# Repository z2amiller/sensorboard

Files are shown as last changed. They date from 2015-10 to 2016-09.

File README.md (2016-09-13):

# sensorboard
Sensor board using ESP8266
==========================

This is a simple sensor board using an ESP8266.

It is designed to run from 6 volts, or 4xAA batteries.  The software uses the
deep sleep functions of the ESP8266 for power savings, and applies power to the
sensors only when the ESP8266 is powered on.  It posts the sensor data to a 
[prometheus](http://prometheus.io/) [pushgateway](https://github.com/prometheus/pushgateway).
A copy of this sensor has run for more than two months on 4xAA batteries.
Longer life can be achieved by using a longer sleep interval; the ESP8266
consumes quite a bit of power at bootup and when communicating over wifi.

Hardware:
---------

* [ESP8266](https://github.com/esp8266/Arduino) is a fully featured wifi
  module with embedded microcontroller.  This project can make use of the
  [ESP-07](http://www.banggood.com/ESP8266-ESP-07-Remote-Serial-Port-WIFI-Transceiver-Wireless-Module-p-961247.html)
  module or any of the
  [ESP-12](http://www.banggood.com/ESP8266-ESP-12E-Remote-Serial-Port-WIFI-Transceiver-Wireless-Module-p-980984.html)
  variants - the extra pins at the bottom are unused.  If using the ESP-07
  with the always-on status LED, you may want to desolder / pry off the
  status LED to extend your battery life.
* [DHT22](http://www.electrodragon.com/product/dht22-pre-order-link/) is a
  temperature and humidity sensor.  It is actually the most expensive part
  of this board, even more expensive than the ESP8266.
* [BMP180](http://www.banggood.com/BMP180-Digital-Barometric-Pressure-Sensor-Module-Board-p-930690.html)
  is a barometric pressure and altitude sensor.
* [LMR16006YDDCR](http://www.ti.com/lit/ds/symlink/lmr16006.pdf) is a 600ma
  adjustable voltage switching power regulator.  While much more expensive
  than the LDO, batteries will last ~twice as long.
* [NR4018T100M](http://www.yuden.co.jp/productdata/catalog/en/wound04_e.pdf)
  is the 10uh inductor used as L1.
* [BME280](http://www.mouser.com/ds/2/783/BST-BME280_DS001-11-844833.pdf) is
  an integrated pressure, humidity, and temperature sensor.  Replaces the
  DHT22 and BMP180 in version 4.0.
* Onboard voltage meter to track the battery voltage.  R4 and R5 make up
  the voltage divider so should be 1% or better tolerance that are
  fairly stable with temperature. 
* Everything else on the board is simple and common.
* This board is intended to be hand-solderable. The smallest components are
  0603 and are marked with hand-soldering pads.

Software:
---------

* This is programmed in the Arduino environment.  It includes some standard
  Adafruit libraries (for DHT22 and BMP085).  The newer "unified" sensor
  libraries don't work with the ESP8266 yet, but the older ones work well.
* This sensorboard posts the data to a prometheus gateway for easy graphing
  and alerting.  The code to get the sensor values is pretty straightforward
  and could be pretty easily adapted to other monitoring systems such as
  Thingspeak or MQTT.
* The [prometheus libraries](https://github.com/z2amiller/libraries/tree/master/prometheus)
  libraries are available in my [libraries](https://github.com/z2amiller/libraries)
  repository. The required i2c library is there as well.

Programming:
------------

* The sensorboard has a 6 pin programming header, and included in this
  repository is a sensorboard\_programmer module intended to be connected to
  this programming header. 
* The sensorboard programmer pulls out the reset and programming pins.  To
  flash a new software version, connect the programmer and press and hold
  the 'PROG' button while hitting reset.  This will reboot the ESP8266 into
  flash mode.
* The sensorboard is designed to use this
  [CP2102 board](http://www.banggood.com/5Pcs-CJMCU-CP2102-USB-To-TTLSerial-Module-UART-STC-Downloader-p-980102.html)
  for the USB interface, and
  [these](http://www.banggood.com/100pcs-Mini-Micro-Momentary-Tactile-Tact-Switch-Push-Button-DIP-P4-p-917570.html)
  cheap tactile switches.  That USB module solders right into the programmer
  board but you could also wire up any USB breakout that supports 3.3 volts.
* Unfortunately the configuration is part of the code.  You'll have to change
  some of the constants in the code to use your wifi SSID/password,
  prometheus pushgateway, etc.

Versions:
---------

Check out the following branches for these released versions:

* [sensorboard-4.0](https://github.com/z2amiller/sensorboard/tree/sensorboard-4.0)
  [oshpark](https://oshpark.com/shared_projects/D1xuf056) UNTESTED:
  Replace the DHT22 and BMP180 with a BME280.  No longer hand-solderable,
  needs a hot air station for the FGA-8 footprint BME280.
* [sensorboard-3.1](https://github.com/z2amiller/sensorboard/tree/sensorboard-3.1)
  [oshpark](https://oshpark.com/shared_projects/4DUu3wyO) TESTED:
  Sensorboard with a switching power supply. Higher parts cost but ~1.6x
  battery life.
* [sensorboard-2.2](https://github.com/z2amiller/sensorboard/tree/sensorboard-2.2)
  [oshpark](https://oshpark.com/shared_projects/rGc3bDv8) TESTED:
  Sensorboard using a LDO for simple build and lower parts cost.

More Links:
-----------

* Order the [sensorboard programmer](https://oshpark.com/shared_projects/fjlzVR1e)
  on OSHPark!
* Check out the [ESP8266 commmunity](http://reddit.com/r/ESP8266) on Reddit!

TODO(z2amiller):
---------------

* Add a picture of the sensorboard in action.
* Add some screenshots of Prometheus graphs.
* Create a prometheus setup tutuorial.
* Create a prometheus dashboard for the ESP8266 sensor data.
* Finish up the code for sensorboard-4.0 with the BME280 sensor.
* Create a sensorboard programmer with a regulator to power the ESP8266
  through the 3v3 pin while programming.

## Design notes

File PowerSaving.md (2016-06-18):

# Power Saving tips for the ESP8266

## Software Tips

### Use DeepSleep.

This is the #1 recommendation when designing a low power ESP8266 application.
Note that this requires hardware changes, too.  GPIO16 must be tied to the RST
pin, and RST should be pulled HIGH externally.  The ESP8266 will pull GPIO16
LOW to reset the chip once the deep sleep timer expires.

Note that this means that the chip is totally reset when coming out of deep
sleep.

Example:
```C++
void sleepFunc() {
  // If this sleep happened because of timeout, clear the
  // Wifi settings.  (Maybe the AP channel changed, etc)
  if (elapsed >= MAX_LOOP_TIME_MS) {
    WiFi.disconnect();
  }
  ESP.deepSleep(480000000, WAKE_RF_DEFAULT);
  // It can take a while for the ESP to actually go to sleep.
  // When it wakes up we start again in setup().
  delay(5000);
}
```

### Do not call WiFi.begin() in setup().

The ESP8266 chip saves the last known wifi settings.  Calling WiFi.begin()
wipes those out.  By calling WiFi.begin() only when it was needed, I shaved
more than 2 seconds from the average amount of time it takes to associate with
the AP.  WiFi.begin() should be called only if the saved SSID does not match
the configured SSID.  You can check the configured SSID with the WiFi.SSID()
call.  Also, it is good practice to clear the saved WiFi settings if the timer
expires.  (See next section "Use watchdog timers")

Example:
```C++
#define WIFI_SSID           "Embedded Pie"
void setup(void) {
  ...
  if (WiFi.SSID() != WIFI_SSID) {
    WiFi.begin(WIFI_SSID, WIFI_PASSWORD);
    WiFi.persistent(true);
    WiFi.setAutoConnect(true);
    WiFi.setAutoReconnect(true);
  }
  ...
}
```

### Use watchdog timers.

Set a timer for the maximum amount of time your polling loop
should run.  This will prevent your device from sitting there for
hours at a time with the WiFi radio on trying to associte if your
AP is down, for example.  The ESP8266 has a built-in Ticker that
takes a timeout and a callback.

Example:
```C++
Ticker sleepTicker;
void setup(void) {
 sleepTicker.once_ms(120000, &sleepFunc)
 ...
}
```

## Hardware Tips

### Eliminate "power" or other always-on LEDs.

Some ESP modules (ESP-07) have an always on "power" LED.  These take around
10mA of current to run, or about 200 hours to drain a single AA battery.  If
you have a status LED on board, disable it by de-soldering it or cutting the
traces.  I have done this on an ESP-07 without affecting the module.

The LED on ESP-12x modules only blinks during serial transmission,
which is infrequent enough not to worry about.

### If using a linear regulator, use one with low quiescent current.

This means no [AMS1117](http://www.advanced-monolithic.com/pdf/ds1117.pdf)
linear regulator which has a quiescent current of 5mA.  Look for low quiescent
current parts.  If you are using a linear regulator, the
[SPX3819M5](https://www.exar.com/content/document.ashx?id=615)
has a fairly low quiescent current of 90uA and a wide voltage range -
up to 16V.  At 90uA, it will take about about two and a half years to
discharge AA batteries.

Other good choices for ESP8266 regulators:

* [MCP1700](http://ww1.microchip.com/downloads/en/DeviceDoc/20001826C.pdf)
  (up to 6V at 1.6uA quiescent) or the
  [MCP1702](http://ww1.microchip.com/downloads/en/DeviceDoc/22008E.pdf)
  (up to 13.2V at 2.0uA quiescent).  Both of these regulators can
  supply 250mA constant and short 500mA bursts, which is perfect for
  the ESP8266 with its short bursts of current draw while transmitting.
  These are available in fixed 3.3V versions.  Available in both surface
  mount and TO-92 packages for under $US0.50 in single quantity.

* [HT73333-A](http://www.angeladvance.com/HT73xx.pdf) is a fixed 3.3V
  250mA regulator with a 4uA quiescent current available cheaply from
  AliExpress.  Also available in both surface mount and TO-92 packages.

### Supply power to sensors from a GPIO pin if the draw is low enough.

Sensors such as the DHT22 and BMP180 have a non-trivial quiescent current,
especially the BMP180 in
[module form](http://www.electrodragon.com/product/bmp180-barometric-pressure-sensor-board/)
which has an integrated linear regulator with a 80uA quiescent current.  The
ESP8266 GPIO pins can source/sink a few mA, which is enough to drive these
sensors so by powering the sensors from a pin, the sensors are only running
when the chip is on.

Some sensors like the DHT22 take 1-2 seconds after power is applied to give a
reading, so this approach can have downsides.

### Use a low quiescent current switching power regulator.

This complicates the build but is significantly more efficient.  Using a linear
regulator, if your ESP is drawing 70mA at 3.3v, it will also draw 70mA at 6v,
with the regulator burning the extra power as heat.

When using a switching regulator, the draw becomes lower by a ratio of the
output to input voltage.  Assuming a 90% efficient switching regulator and a 6v
supply, drawing 70mA of 3.3v becomes:

    70mA * (3.3 / 6) * (1 / 0.9) = ~43mA input current @ 6V.

This is significant because even though the device is only on for a short
amount of time, overall power consumption is dominated by the device in the
active state.  For example, if the device is drawing 100uA (0.1mA) while
sleeping and 70mA while active, sleeps for 8 minutes between cycles, and is on
for 10 seconds every cycle:

    AA batteries = ~2000mAhours or 7.2 million mA seconds

Linear regulator:
    480 seconds * 0.1mA = 48mA seconds
    10 seconds * 70mA = 700mA seconds

    748 mA seconds / cycle = ~9,700 cycles on a AA battery, or about
    54 days on 4xAA batteries.

Switching regulator:
    480 seconds * 0.1mA = 48mA seconds
    10 seconds * 43mA = 430mA seconds

    478 mA seconds / cycle = ~15,000 cycles on a AA battery, or about
    85 days on 4xAA batteries.

Good switching regulators for the ESP8266:

* The [LMR16006](http://www.ti.com/lit/ds/symlink/lmr16006.pdf) is an adjustable
  output 600mA switching regulator that can take a very wide range of input
  voltages, up to 60V.  It has a quiescent current of 28uA.

* The [LM3671](http://www.ti.com/lit/ds/symlink/lm3671.pdf) is available in
  both fixed and adjustable models.  It only accepts up to 6V input but is
  perfect for a 5v or single LiPo powered device.  It has a quiescent current
  of only 16uA.

### Do not use all-in-one boards like the WeMos D1 Mini or NodeMCU.

These boards are excellent for prototyping, but they hae some real downsides
when deployed in a low power application.

First, they often have cheap regulators with high quiescent current, like the
AMS1117. (See above why this is bad).

Worse, these boards have an "always on" USB UART bridge like a CP2102.  The
CP2102 datasheet says that the quiescent current is around 20mA!  This means
that even if you have put your ESP8266 is in deep sleep mode, the other stuff
on the board is conspiring to draw 20-25mA and will run your batteries down
quickly.

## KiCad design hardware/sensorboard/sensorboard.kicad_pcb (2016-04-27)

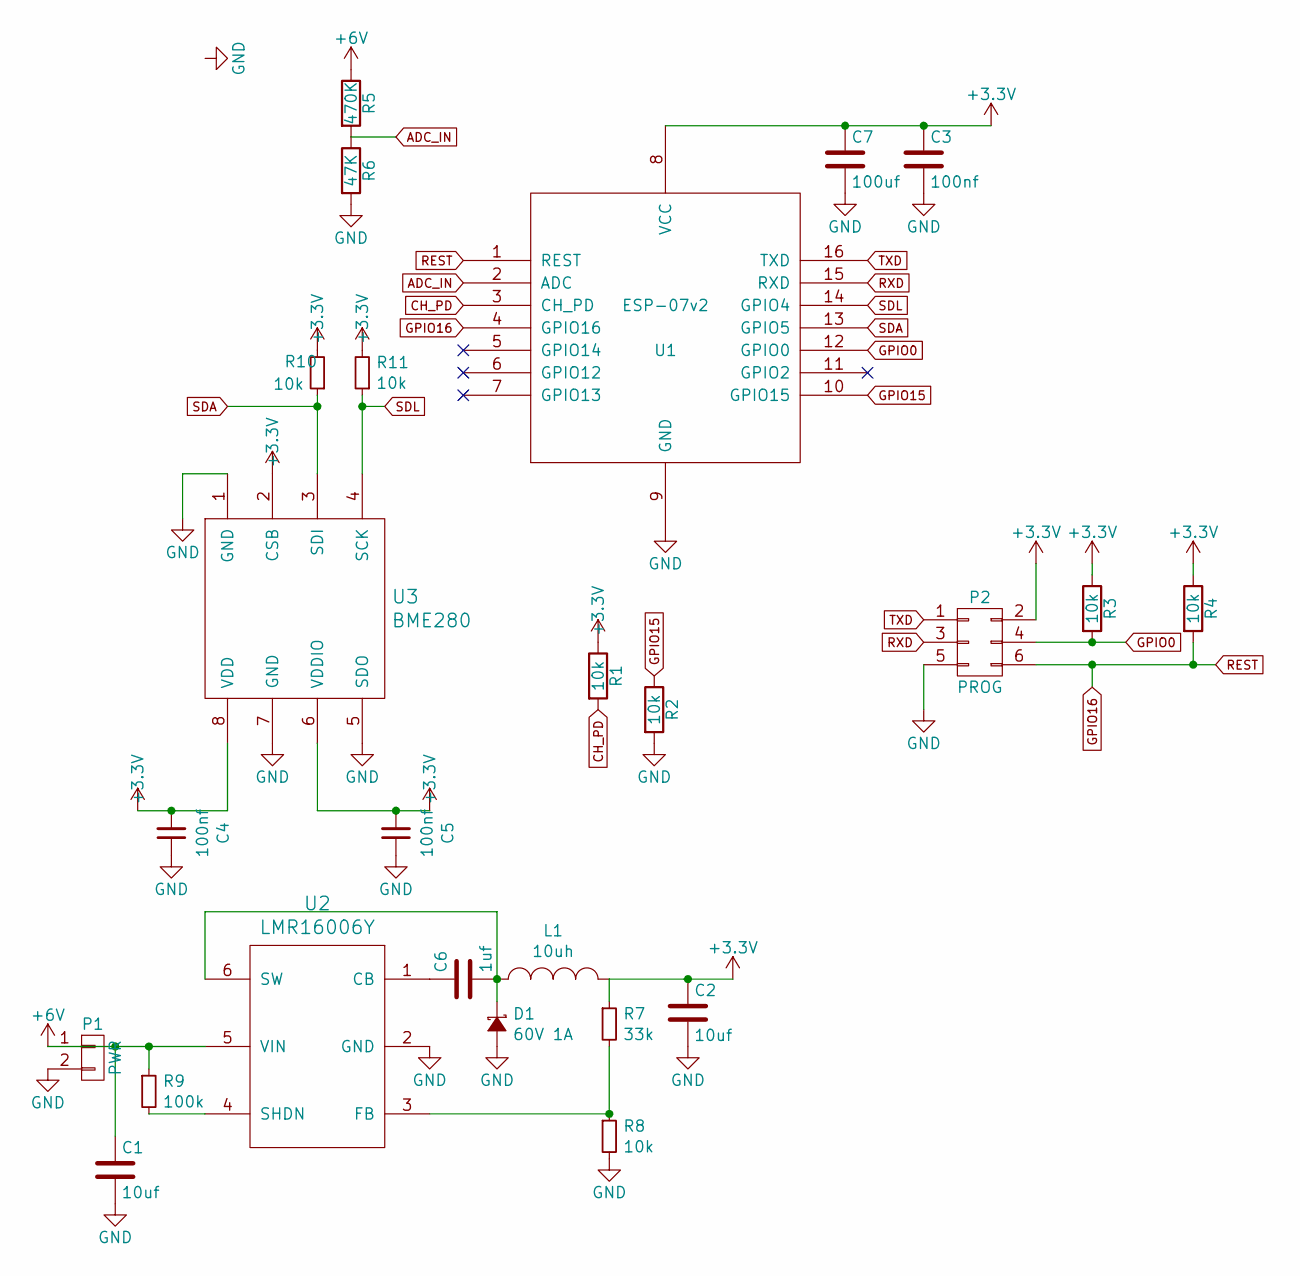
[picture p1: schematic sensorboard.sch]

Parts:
C1, C2: 10uf; C_0805_HandSoldering
C3, C4, C5: 100nf; C_0603_HandSoldering
C6: 1uf; C_0603_HandSoldering
C7: 100uf; TantalC_SizeD_EIA-7343_HandSoldering
D1: 60V 1A; SOD-123
L1: 10uh; NR8040_HandSoldering
P1: PWR; Pin_Header_Straight_1x02
P2: PROG; Pin_Header_Straight_2x03
R1, R2, R3, R4, R8, R10, R11: 10k; R_0603_HandSoldering
R5: 470K; R_0603_HandSoldering
R6: 47K; R_0603_HandSoldering
R7: 33k; R_0603_HandSoldering
R9: 100k; R_0603_HandSoldering
U1: ESP-07v2; ESP-12
U2: LMR16006Y; SOT-23-6
U3: BME280; FGA8

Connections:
+3V3: C2.1, C3.1, C4.2, C5.2, C7.1, L1.2, P2.2, R1.1, R3.1, R4.1, R7.1, R10.2, R11.2, U1.8 (VCC), U3.2 (CSB), U3.6 (VDDIO), U3.8 (VDD)
+6V: C1.1, P1.1, R5.1, R9.1, U2.5 (VIN)
ADC_IN: R5.2, R6.1, U1.2 (ADC)
CH_PD: R1.2, U1.3 (CH_PD)
GND: C1.2, C2.2, C3.2, C4.1, C5.1, C7.2, D1.2 (A), P1.2, P2.5, R2.2, R6.2, R8.2, U1.9 (GND), U2.2 (GND), U3.1 (GND), U3.5 (SDO), U3.7 (GND)
GPIO0: P2.4, R3.2, U1.12 (GPIO0)
GPIO15: R2.1, U1.10 (GPIO15)
GPIO16: P2.6, R4.2, U1.1 (REST), U1.4 (GPIO16)
unnamed: C6.1, U2.1 (CB)
unnamed: C6.2, D1.1 (K), L1.1, U2.6 (SW)
unnamed: R7.2, R8.1, U2.3 (FB)
unnamed: R9.2, U2.4 (SHDN)
RXD: P2.3, U1.15 (RXD)
SDA: R10.1, U1.13 (GPIO5), U3.3 (SDI)
SDL: R11.1, U1.14 (GPIO4), U3.4 (SCK)
TXD: P2.1, U1.16 (TXD)

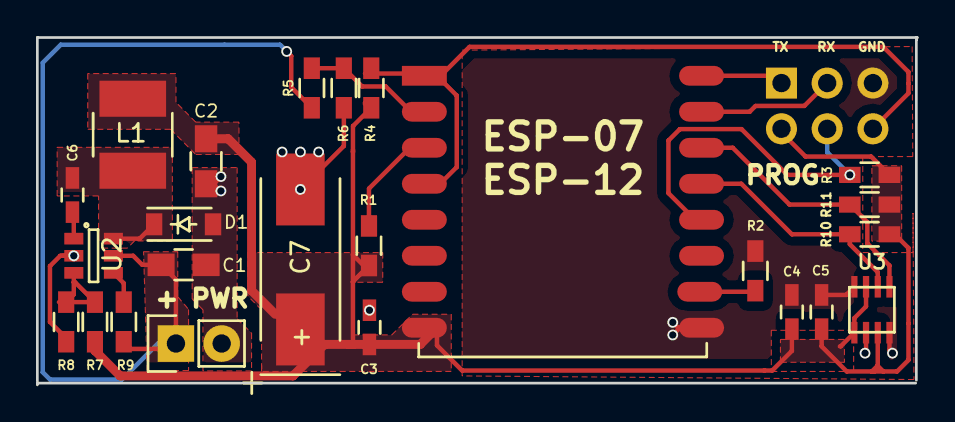
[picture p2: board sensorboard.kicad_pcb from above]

Board: 2 copper layers, 48.9 x 19.3 mm, 25 parts (1 on the bottom side), 16 nets.

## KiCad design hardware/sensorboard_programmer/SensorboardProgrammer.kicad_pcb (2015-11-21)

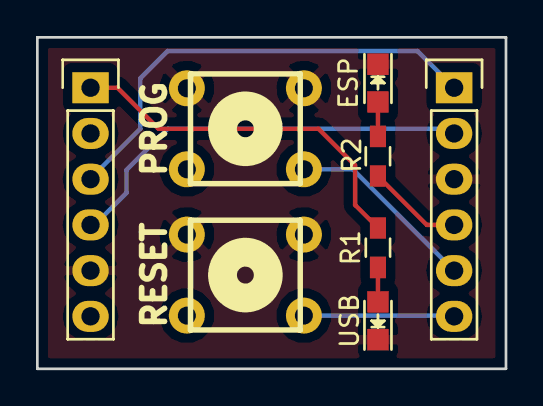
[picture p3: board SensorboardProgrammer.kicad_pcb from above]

Board: 2 copper layers, 26.0 x 18.4 mm, 8 parts (0 on the bottom side), 9 nets.

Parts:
ESP: ESP; LED-0805
P2: CONN_01X06; Pin_Header_Straight_1x06
PROG: SW_PUSH; PCB_PUSH
R1, R2: 100 ohm; R_0603_HandSoldering
RESET: SW_PUSH; PCB_PUSH
USB: USB; LED-0805
USB MODULE: CONN_01X06; Pin_Header_Straight_1x06

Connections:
GND: ESP.1, P2.3, PROG.2, PROG.4, RESET.2, RESET.4, USB.1, USB MODULE.5
unnamed: R1.1, USB.2
unnamed: ESP.2, R2.1
unnamed: R1.2, USB MODULE.1
unnamed: P2.4, R2.2
unnamed: P2.5, PROG.3
unnamed: P2.6, RESET.3
RXI: P2.1, USB MODULE.3
TXO: P2.2, USB MODULE.4

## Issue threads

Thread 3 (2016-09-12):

Link to prometheus arduino library used in this project

croisez, 2016-09-12:
Hi, could you document the link to the prometheus Arduino library used in this project?

z2amiller, 2016-09-13:
Added a link to the README.md.  (https://github.com/z2amiller/sensorboard/commit/1cc4190ea89385d12b81b523408ae3b3c466286c)   The required libraries are in my libraries repo (https://github.com/z2amiller/libraries).  Thanks for filing an issue and let me know if you need any other help setting it up.

Closed 2016-09-13.

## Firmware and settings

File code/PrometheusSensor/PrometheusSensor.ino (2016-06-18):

#include <ESP8266WiFi.h>
#include <WiFiClient.h>
#include <Ticker.h>
#include <DHT.h>
#include <SPI.h>
#include <Wire.h>
#include <Adafruit_Sensor.h>
#include <Adafruit_BME280.h>
#include <prometheus.h>
#include <i2cbase.h>
 
#define WIFI_SSID           "Embedded Pie"
#define WIFI_PASSWORD       "embedded"

#define SERVER_IP           "10.1.20.200"
#define SERVER_PORT         9091

#define METRICS_JOB         "env_sensor"
#define METRICS_INSTANCE    "MasterBathroom"

#define MAX_LOOP_TIME_MS     10000

#define SEALEVELPRESSURE_HPA (1013.25)


const String metrics_url = "/metrics/job/" + String(METRICS_JOB) +
                           "/instance/" + String(METRICS_INSTANCE);

ADC_MODE(ADC_TOUT);

Ticker sleepTicker;
Adafruit_BME280 bme;

unsigned long startTime;

void sleepyTime() {
  const int elapsed = millis() - startTime;
  Serial.printf("Sleeping. Loop took %d ms\n", elapsed);
  // If this sleep happened because of timeout, clear the
  // Wifi state.
  if (elapsed >= MAX_LOOP_TIME_MS) {
    WiFi.disconnect();
  }
  ESP.deepSleep(480000000, WAKE_RF_DEFAULT);
  // It can take a while for the ESP to actually go to sleep.
  // When it wakes up we start again in setup().
  delay(5000);
}

void waitForWifi() {
  Serial.print("Connecting to WiFi.");
  // Wait for connection
  while (WiFi.status() != WL_CONNECTED) {
    Serial.print(".");
    delay(100);
  }
  Serial.println(" Done");
  Serial.println("ESP8266 Weather Sensor");
  Serial.printf("Connected to %s\n", WIFI_SSID);
  Serial.print("IP address: ");
  Serial.println(WiFi.localIP());
}

void setup(void)
{
  startTime = millis();
  sleepTicker.once_ms(12000, &sleepyTime);
  Serial.begin(115200);
  Serial.println();
  Wire.pins(4,5);
  if (!bme.begin(0x76)) {
    Serial.println("Could not find a valid BME280 sensor, check wiring!");
    while (1);
  }
  // Use the i2cbase library to directly modify some of the
  // BME280 configuration registers.
  i2cBase bconfig(0x76);
  // 1x sampling for humidity.
  bconfig.write8(0xF2, 0x01);
  // 1x sampling for temperature and pressure, sleep mode on.
  bconfig.write8(0xF4, 0x24);
  // With sleep mode on, change to 1s sampling.
  bconfig.write8(0xF5, 0xA0);
  // 8x sampling for temperature and pressure, normal mode.
  bconfig.write8(0xF4, 0x27);
  Serial.println("Using saved SSID: " + WiFi.SSID());
  if (WiFi.SSID() != WIFI_SSID) {
    Serial.println("Configuring persistent wifi...");
    WiFi.begin(WIFI_SSID, WIFI_PASSWORD);
    WiFi.persistent(true);
    WiFi.setAutoConnect(true);
    WiFi.setAutoReconnect(true);
  } else {
    Serial.println("Using saved wifi info...");
  }
}

bool isValidHumidity(const float humidity) {
  return (!isnan(humidity) && humidity >= 0 && humidity <= 100);
}

bool isValidTemp(const float temp) {
  return (!isnan(temp) && temp >= -100 && temp <= 212);
}

float tempF(const float temp) {
  return 1.8F * temp + 32;
}

MapMetric makeMetric(const String& name, const float value) {
  MapMetric m = MapMetric("env_sensor_" + name, "location");
  m.Add(METRICS_INSTANCE, value);
  return m;
}

void loop(void)
{
  PrometheusClient pclient =
      PrometheusClient(SERVER_IP, SERVER_PORT,
                       METRICS_JOB, METRICS_INSTANCE);
                           
  float temp = bme.readTemperature();
  float humidity = bme.readHumidity();
  while (!(isValidTemp(temp) && isValidHumidity(humidity))) {
    delay(100);
    temp = bme.readTemperature();
    humidity = bme.readHumidity();
  }

  const int bmeTime = millis() - startTime;
  Serial.printf("BME read took %d ms\n", bmeTime);
  waitForWifi();
  const int wifiTime = millis() - (startTime + bmeTime);
  Serial.printf("WiFi init took an additional %d ms\n", wifiTime);
 
  pclient.AddMetric(makeMetric("humidity", humidity));
  pclient.AddMetric(makeMetric("tempF", tempF(temp)));
  pclient.AddMetric(makeMetric("battery_millivolts", analogRead(A0) * 11.0));
  pclient.AddMetric(makeMetric("free_heap", ESP.getFreeHeap()));
  pclient.AddMetric(makeMetric("bmp_tempC", bme.readTemperature()));
  pclient.AddMetric(makeMetric("pressure", bme.readPressure()));
  pclient.AddMetric(makeMetric("altitude", bme.readAltitude(SEALEVELPRESSURE_HPA)));
  pclient.AddMetric(makeMetric("loop_time", float(millis() - startTime)));
  pclient.PrintSerial();
  pclient.Send();
  sleepyTime();
} 

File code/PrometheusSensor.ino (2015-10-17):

#include <ESP8266WiFi.h>
#include <WiFiClient.h>
#include <DHT.h>
#include <Wire.h>
#include <Adafruit_BMP085.h>
#define DHTTYPE DHT22

// Note that sometimes GPIO4 and GPIO5 are switched on different
// models of the ESP8266.  (And sometimes they are even labelled
// incorrectly!)
#define DHTPIN  5
#define DHTPWR  13
 
#define WIFI_SSID           "Embedded Pie"
#define WIFI_PASSWORD       "embedded"

#define SERVER_IP           "10.1.20.200"
#define SERVER_PORT         9091

#define METRICS_JOB         "env_sensor"
#define METRICS_INSTANCE    "LivingRoom"

const String metrics_url = "/metrics/job/" + String(METRICS_JOB) +
                           "/instance/" + String(METRICS_INSTANCE);

ADC_MODE(ADC_VCC);
 
// Initialize DHT sensor NOTE: For working with a faster than ATmega328p 16 MHz
// Arduino chip, like an ESP8266, you need to increase the threshold for cycle
// counts considered a 1 or 0.  You can do this by passing a 3rd parameter for
// this threshold.  It's a bit of fiddling to find the right value, but in
// general the faster the CPU the higher the value.  The default for a 16mhz
// AVR is a value of 6.  For an Arduino Due that runs at 84mhz a value of 30
// works.  This is for the ESP8266 processor on ESP-01 
DHT dht(DHTPIN, DHTTYPE, 11); // 11 works fine for ESP8266

Adafruit_BMP085 bmp;

unsigned long previousMillis = 0;
const long interval = 2000;

void setup(void)
{
  Serial.begin(115200);
  // Power on the sensors first.  Both the DHT22 and the bmp180
  // are very low power and can be powered from a ESP8266 GPIO pin.
  pinMode(DHTPWR, OUTPUT);
  digitalWrite(DHTPWR, HIGH);
  dht.begin();
  
  // Connect to WiFi network
  WiFi.begin(WIFI_SSID, WIFI_PASSWORD);
  Serial.print("\n\r \n\rConnecting to WiFi.");
  // Wait for connection
  while (WiFi.status() != WL_CONNECTED) {
    delay(250);
    Serial.print(".");
  }
  Serial.println("");

  // Initialize the Software I2C library to talk to the BMP180 sensor.
  Wire.pins(12, 14);
  if (!bmp.begin()) {
    Serial.println("BMP init error!");
  }
  Serial.println("ESP8266 Weather Sensor");
  Serial.print("Connected to ");
  Serial.println(WIFI_SSID);
  Serial.print("IP address: ");
  Serial.println(WiFi.localIP());
}

String makeSensorVar(const String& name) {
  return "# TYPE env_sensor_" + name + " gauge\n" +
         "env_sensor_" + name + "{chipid=\"" + String(ESP.getChipId()) +
         "\",location=\"" + METRICS_INSTANCE + "\"}";
}

void sendMetrics(const String& metricString) {
  WiFiClient client;
  if (!client.connect(SERVER_IP, SERVER_PORT)) {
    Serial.println("Connection error.");
    return;
  }
  int content_length = metricString.length();
  client.print(
    "POST " + metrics_url + " HTTP/1.1\r\n" +
    "Host: " + String(SERVER_IP) + "\r\n" +
    "Connection: close\r\n" +
    "Content-Length: " + String(content_length) + "\r\n" +
    "\r\n" +
    metricString);
  delay(100);
  while(client.available()) {
    String line = client.readStringUntil('\r');
    Serial.println("Server response: " + line);
  }
  client.stop();
}

bool isValidHumidity(float humidity) {
  return (!isnan(humidity) && humidity >= 0 && humidity <= 100);
}

bool isValidTemp(float temp) {
  return (!isnan(temp) && temp >= -100 && temp <= 212);
}

void loop(void)
{
  float temp, humidity;
  for (int i = 0; i < 4; i++) {
    temp = dht.readTemperature(true);
    if (!isValidTemp(temp)) {
      delay(250);
      continue;
    }
    break;
  }
  for (int i = 0; i < 4; i++) {
    humidity = dht.readHumidity();
    if (!isValidHumidity(humidity)) {
      delay(250);
      continue;
    }
    break;
  }
  
  String out;
  if (isValidHumidity(humidity)) {
    out += makeSensorVar("humidity") + " " + String(humidity) + "\n";
  }
  if (isValidTemp(temp)) {
    out +=  makeSensorVar("tempF") + " " + String(temp) + "\n";
  }
  out += makeSensorVar("battery_millivolts") + " " + String(ESP.getVcc()) + "\n";
  out += makeSensorVar("free_heap") + " " + String(ESP.getFreeHeap()) + "\n";
  out += makeSensorVar("bmp_tempC") + " " + String(bmp.readTemperature()) + "\n";
  out += makeSensorVar("pressure") + " " + String(bmp.readPressure()) + "\n";
  out += makeSensorVar("altitude") + " " + String(bmp.readAltitude()) + "\n";
  Serial.println(out);
  sendMetrics(out);
  // Power off the sensor while the esp is in deep sleep.
  digitalWrite(DHTPWR, LOW);
  ESP.deepSleep(120000000, WAKE_RF_DEFAULT);
  // It can take a while for the ESP to actually go to sleep.
  // When it wakes up we start again in setup().
  delay(5000);
} 

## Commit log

2015-10-17 Move sensorboard stuff to dedicated repository.
    [SensorboardProgrammer.kicad_pcb, SensorboardProgrammer.sch, sensorboard.kicad_pcb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]
2015-10-24 Change footprint of power connector, move ino file
    [sensorboard.kicad_pcb]
2015-10-25 Read voltage from A0 instead of internal VCC.
2015-10-25 Measure the actual battery voltage on ADC pin.
    [_saved_sensorboard.sch, sensorboard.sch]
2015-10-25 Remove backup file.
    [_saved_sensorboard.sch]
2015-10-25 Fix scaling factor of ADC.
    [PrometheusSensor.ino]
2015-10-31 Change some footprints.
    [sensorboard.sch]
2015-10-31 Change some footprints from 0805 to 0603.
    [sensorboard.kicad_pcb]
2015-11-04 Better silkscreening and status LEDs.
    [SensorboardProgrammer.kicad_pcb, SensorboardProgrammer.sch]
2015-11-04 A few more silkscreen changes.
    [SensorboardProgrammer.kicad_pcb]
2015-11-04 Add LEDs and improved silkscreens.
    [SensorboardProgrammer.kicad_pcb, SensorboardProgrammer.sch]
2015-11-05 Add MIT license for sensorboard hardware and code.
2015-11-05 Add real documentation for the sensorboard project.
2015-11-08 Changed power connector, improved silkscreen.
    [sensorboard.kicad_pcb]
2015-11-08 Improved silkscreening for sensorboard.
    [sensorboard.kicad_pcb]
2015-11-21 Change bmp180 label visibility.
    [sensorboard.kicad_pcb]
2015-11-21 Fix silkscreen error - PRG and 3v3 were reversed..
    [SensorboardProgrammer.kicad_pcb]
2016-02-27 Attempt one at switching power supply.
    [sensorboard.sch]
2016-02-28 Fix up silkscreening
    [sensorboard.kicad_pcb]
2016-02-28 Fix up the bottom edge cuts
    [sensorboard.kicad_pcb]
2016-02-28 Bro do you even switch
    [sensorboard.kicad_pcb]
2016-02-28 Fix up the 3v3 traces
    [sensorboard.kicad_pcb]
2016-02-28 Some silkscreen cleanup
    [sensorboard.kicad_pcb]
2016-03-05 Use smaller inductor, shrink board a little
    [sensorboard.kicad_pcb]
2016-03-05 Fix some silkscreens
    [sensorboard.kicad_pcb]
2016-03-05 Better routing of 3v3
    [sensorboard.kicad_pcb]
2016-03-05 Remove extra 3v3 via, add better ground connection
    [sensorboard.kicad_pcb]
2016-04-03 Refactor to use prometheus lib and timers.
2016-04-04 Use bme280 for sensor - initial commit
    [sensorboard.kicad_pcb, sensorboard.sch]
2016-04-04 Fix sensor placement and improve silkscreens
    [sensorboard.kicad_pcb, sensorboard.sch]
2016-04-04 Fixed soldermask around the bme280
    [sensorboard.kicad_pcb, sensorboard.sch]
2016-04-26 Add a file talking about low power ESP8266.
2016-04-26 Fixed some silkscreens, added BOM.
    [sensorboard.kicad_pcb, sensorboard.sch]
2016-04-30 Code for sensorboard 4.0 using adafruit bme280 lib.
2016-06-18 More regulator examples, talk about NodeMCU.
